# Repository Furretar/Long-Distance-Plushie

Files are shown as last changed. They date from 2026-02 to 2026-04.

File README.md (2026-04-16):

# Overview

#### The device has 4 modes: active, normal checks, slow checks, and off.
- After connecting to a network and MQTT, it starts in normal mode and wakes up every 15 seconds to check for commands.
- After reading a command, it will become active and stay awake for 2 minutes. It can recieve messages instantly in this mode.
- After 2 days of inactivity, the device enteres slow mode, and only checks every 30 seconds. (these values can be changed in the config)
- After sending the command `off`, the device will go into deep sleep, and can only be woken up with the button.

#### The LED has 6 colors.
- Red: Connecting to WiFi
- Blue: Connecting to MQTT
- Green: Active
- Yellow: Both devices are active
- White: This device is vibrating
- Magenta: Other device is vibrating
- Cyan: Sending vibrate command, other device should wake up soon

#### WiFi
The ESP32 communicates over WiFi using MQTT. It has a hardcoded default WiFi network. It will automatically try to connect to this when it first starts up. You can add networks to the config via the serial terminal or an MQTT command. After connecting to a new network, the default network is changed to the new network. The device will try 2 times to connect to the last connected network. If these attempts both fail, it will try every other network saved in the config. If it connects to a new network, it will move that network to the front of the list and set the last connected network. It repeats this process 3 times, then it gives up and goes to sleep for 2x the slow check interval (60 seconds) before trying again. If the device can't connect to any network, it will need to be connected to a computer with [Arudino IDE](https://www.arduino.cc/en/software/) to send a command to add a network.

#### MQTT
The LED displays the device's status while it's trying to connect to the MQTT server (and can't send any messages). It will shine red while connecting to WiFi, and shine blue while connecting to MQTT. After failing an MQTT connection 2 times, the device will go sleep for 2x the slow check interval (60 seconds) before trying again. Pushing the button will make it attempt a connection again.

#### Button
While connected, the button will trigger the other device's motor at 20% strength (can be changed). If the button is held for longer than 10 seconds the motor will automatically turn off.

#### Battery
The battery can be recharged by plugging in the device, and the voltage can be seen in the MQTT info topic. It's estimated the battery life would last 20 days with 1 hour of active time and 23 hours of normal checks a day. It's also estimated the battery is about to die at 3.3 volts.

# MQTT Broker Setup
If you don't want self host your MQTT broker, I recommend the service [EMQX](https://www.emqx.com/en/MQTT/public-MQTT5-broker). The free tier allows 1,000 devices to be connected, with 1,000,000 active minutes and 1 GB of data per month. This should be way more than enough for this project. Just make an account, make a project, set a username and password in `Access Control->Authorization` (set both to `a` so it works automatically with this code), and you can access the MQTT host in `Deployment Overview`. Just set the host url in the `LDP-ESP32-Code.ino` file near the top.

Example: `const char* defaultMqttHost = "lc600a99.ala.us-east-1.emqxsl.com"`



# Sending Commands:
Commands can be sent to the device through the `Iot MQTT Panel` app. You can also see the status of each device, and they will display messages about their mode, when they vibrate, and current voltage. 

- the dashboard settings require a name (anything)
- an ID (anything)
- a broker address (example): `lc600a99.ala.us-east-1.emqxsl.com`
- a port: `8883`
- network protocol: TCP-SSL
- and in additional options, a username: `a`
- and a password: `a`
  
After connecting, add 5 panels. The available topics are `ESP32_1`, `ESP32_2`, and `info`. add a text input and output for ESP32_1 and ESP32_2, and a text output for info. 

# Commands
open the IoT MQTT Panel app on iOS or android to send commands through MQTT, or send commands in serial monitor in Arudino IDE

`run` - toggles the motor on

`run 100` - toggles the motor with 100% strength

`stop` - toggles the motor off

`print config` - prints config to the terminal

`config [key] [value]`, example: `config strength 100` - changes value of the entry in the config

`delete config` - deletes the config and recreates it with default values

`add network [name] [password]` - adds a network with the name/ssid and password

`delete network [ssid]` - deletes the WiFi network entry with the listed name/ssid

`print voltage` - prints voltage to the terminal and info topic MQTT

`sleep` - puts device to sleep, will wake up after normal check time

`off` - puts device to sleep, can only be woken with the button WIP

`var all` - prints the value of global variables, for debugging

You may need to wait to send a command if the device is trying to connect to MQTT.

# Construction Notes
- To build this project, you can reference the item list below and `LDP-Wiring.svg` file in this repository. There is also a 3D model file `LDP-housing-model.stl` that can be printed to house the project once constructed.
- [info about the ESP32 xiao c3.](https://wiki.seeedstudio.com/XIAO_ESP32C3_Getting_Started/)
- The LED can't use pins D9 (GPIO21) or D7 (GPIO20) because they can't be turned off while asleep, and will cause the LED to dimly glow. 
- There is tape on the LED to prevent the pins from touching. This isn't strictly necessary, and anything to stop the pins from touching will work. 
- ESP32 battery wires should all be lead out of the back, away from the usb port. there should be 2 pairs of wires on the BAT-/BAT+ pads, 1 pair connected to the battery holder, and 1 pair of jumper cables to power the board. (If you solder another pair of 220k resistors on the pads, you don't need to attach the 220k resistors as shown in the picture [as described here](https://wiki.seeedstudio.com/XIAO_ESP32C3_Getting_Started/#check-the-battery-voltage).)
  
pin_map-2

# Wiring Pictures
Uploading LDP-Wiring.svg…

Unfortunately I made 2 mistakes in my soldering in these examples. You should refer to the fritzing model instead. The blue and purple wires are unnecessary, you only need 1 pair of jumper cables attached to the BAT+/BAT- pads on the ESP32. The header pins are also crooked on my ESP32 in this example. 

pin_map-2

pin_map-2

pin_map-2

pin_map-2

# Item list
[seeed ESP32 xiao c3](https://www.amazon.com/dp/B0DGX3LSC7/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)

[8000-16000RPM Motor](https://www.amazon.com/dp/B07KYLZC1S/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)

[2 inch arcade buttons](https://www.amazon.com/dp/B07V55YPP3/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)

[1￵8￵6￵5￵0 Rechargeable Batter￵y](https://www.amazon.com/dp/B0DF6CPJFR/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)

[18650 Battery Holders](https://www.amazon.com/dp/B0BJV7SK5D/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)

[Common Cathode RGB LEDs](https://www.amazon.com/dp/B077XGF3YR/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)

[mini bread boards](https://www.amazon.com/dp/B09YXQJMTG/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)

[Heat Resistant Polyimide Tape](https://www.amazon.com/dp/B0DZCTB4KG?ref=ppx_yo2ov_dt_b_fed_asin_title&th=1)

[2n2222 transistors](https://www.amazon.com/dp/B07T61SY9Y/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)

[diode](https://www.amazon.com/dp/B0FC2CTBJR/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)

[Breadboard Jumper Wire kit](https://a.co/d/aZJ2nzj)

[resistors](https://www.amazon.com/dp/B0F4P352BB/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)

[header pins](https://www.amazon.com/dp/B07PKKY8BX/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)

# (WIP) Handling Blocked Public Networks
This is an overview to remind myself, this solution is not implemented in the code yet. On some public WiFi networks, the host `emqxsl.com` is blocked, and you will not be able to send any MQTT messages over the network. This is the case on my university's campus WiFi. You can bypass this by hosting a web service that receives the commands and sends them to EMQX. To do this,  I recommend the service [Render.com](https://render.com/). 
- Clone this github repository
- Go to `Projects`
- `Deploy A Web Service`
- Select this repository
- Set `Language` to `Node`
- Set `Root Directory` as `./Optional-MQTT-Bridge`
- Set `Build Command` to `npm install`
- Set `Start Command` to `npm start`

You can now use the web service link `https://example.onrender.com`  to send messages to your MQTT broker. You can send messages using the ESP32 like this:
```
http.begin(client, "https://example.onrender.com/publish");
http.addHeader("Content-Type", "application/json");
http.POST("{\"topic\":\"example_topic\",\"message\":\"hello\"}");
```

Or the command line like this:

`curl -X POST https://long-distance-plushie.onrender.com/publish -H "Content-Type: application/json" -d '{"topic": "example_topic", "message": "hello"}'`

However, there's also a login capture page when sending requests over HTTPS on my university's network. I don't know of a way to navigate the login portal on the ESP32, so one way to bypass this is MAC address spoofing. You can change your computer's MAC address, authenticate the WiFi network, set your ESP32's MAC address to match, then change your computer's MAC address back. There can't be 2 devices with the same MAC address on the same network. I could add a flag to the code to switch to always using the bridge, as well as a variable to store a MAC address. I don't plan on implementing this currently and will test out using a hotspot instead.

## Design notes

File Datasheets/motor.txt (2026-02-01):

DC Coreless Motor Built-in Vibration Waterproof 1.5-3v 8000-16000RPM Motor for Electric Toothbrush 7x25mm 5PCS
Brand 	tatoko
Speed 	16000 RPM
Voltage 	3 Volts
Horsepower 	0.06 Watts
Product Dimensions 	0.27"W x 0.96"H
    Size: 7x25mm:IP67
    Voltage: 1.5-3v Speed: 8000-16000 Power: 0.01-0.06W Torque: 0.3g.cm-3g.cm (NM)

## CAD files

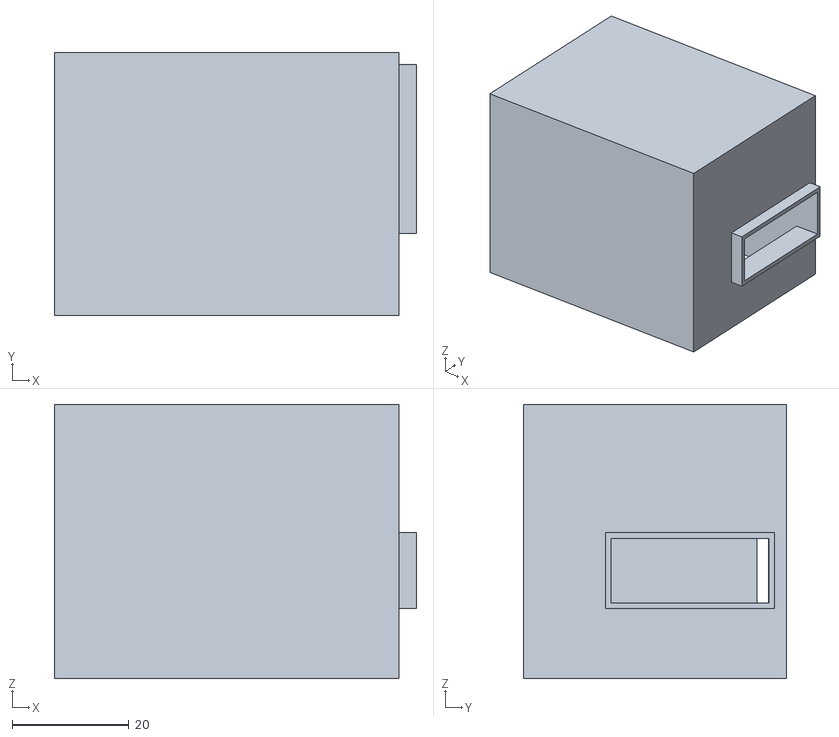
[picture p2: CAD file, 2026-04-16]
LDP-housing-model.stl
62.0 x 45.0 x 47.0

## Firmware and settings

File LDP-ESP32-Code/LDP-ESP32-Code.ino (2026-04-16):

#include <WiFi.h>
#include <PubSubClient.h>
#include <WiFiClientSecure.h>
#include <LittleFS.h>  // for logging
#include <ArduinoJson.h>
#include "esp_sleep.h"  // for deep sleep
#include <time.h>

#define BATTERY_PIN D0
#define MOTOR_PIN D10
#define BUTTON_PIN D1  // GPIO 3, RTC capable/can wake up from deep sleep
#define RED_PIN D5
#define GREEN_PIN D4
#define BLUE_PIN D3

// change for each esp32
const int thisNum = 1;

// change for other setups
const char* defaultMqttHost = "";
const char* userNetwork = "";
const char* userPassword = "";

const int defaultMqttPort = 8883;
const char* defaultMqttUser = "a";
const char* defaultMqttPass = "a";
const char* defaultInfoTopic = "info";

// topics
const int targetNum = thisNum == 1 ? 2 : 1;
String thisTopic = String("esp32_") + String(thisNum);
String targetTopic = String("esp32_") + String(targetNum);
String thisPing = String("ping_") + String(thisNum);
String targetPing = String("ping_") + String(targetNum);

// default config values
const int defaultCheckMqttTime = 100;               // ms, default 200, time awake to read retained mqtt messages
const int defaultStayAwakeAfterCommand = 120;       // seconds, default 120
const int defaultMotorTimeout = 10000;              // ms, default 10,000
const int defaultNormalCheck = 15ULL * 1000000ULL;  // microseconds, default 15,000,000, sleep for this long before waking up to check again
const int defaultSlowCheck = 30ULL * 1000000ULL;    // microseconds, default 30,000,000
const int defaultMaxPwm = 150;                      // out of 255, motor rated for 3 volts but powered by 3.7, default 150
const int defaultBrightness = 20;                   // percent max brightness
const int defaultStrength = 20;                     // percent of max motor strength, default 20
const int defaultTimeUntilSlowCheckMode = 2 * (60 * 60 * 24);

// config variables
RTC_DATA_ATTR int checkMqttTime;
RTC_DATA_ATTR unsigned long stayAwakeAfterCommand;
RTC_DATA_ATTR unsigned long motorTimeout;
RTC_DATA_ATTR unsigned long long normalCheck;
RTC_DATA_ATTR unsigned long long slowCheck;
RTC_DATA_ATTR int maxPwm;
RTC_DATA_ATTR int mqttPort;
RTC_DATA_ATTR char mqttHost[128];
RTC_DATA_ATTR char mqttUser[64];
RTC_DATA_ATTR char mqttPass[64];
RTC_DATA_ATTR char infoTopic[64];
RTC_DATA_ATTR int strength;
RTC_DATA_ATTR int brightness;
RTC_DATA_ATTR char default_ssid[32] = "";
RTC_DATA_ATTR char default_password[64] = "";
RTC_DATA_ATTR time_t timeUntilSlowCheckMode;

// non config rtc
RTC_DATA_ATTR bool debugMqttFailed = false;
RTC_DATA_ATTR bool firstBoot = true;
RTC_DATA_ATTR bool slowCheckMode = false;
RTC_DATA_ATTR time_t timeLastActive;

// global variables
bool offSwitch = false;
bool runMotor = false;
bool clearCommand = false;
bool clearPing = false;
bool variablesSet = false;
bool commandReceivedThisBoot = false;
bool otherAwake = false;
bool mqttConnected = false;
esp_sleep_wakeup_cause_t wakeupReason = esp_sleep_get_wakeup_cause();
volatile bool stayAwake = (wakeupReason == ESP_SLEEP_WAKEUP_GPIO);
int lastButtonState = HIGH;
unsigned long motorStart = 0;
unsigned long mqttConnectTime = 0;
StaticJsonDocument<1024> doc;
WiFiClientSecure wifi;
PubSubClient mqtt(wifi);


// led variables
int currentR = 0;
int currentG = 0;
int currentB = 0;
int bothAwakeR = 70;
int bothAwakeG = 70;
int bothAwakeB = 0;
int thisAwakeR = 0;
int thisAwakeG = 70;
int thisAwakeB = 0;

// sync variable
unsigned long lastPingSent = 0;
unsigned long lastPongReceived = 0;
const int pingInterval = 500;
const int pongTimeout = 2000;  // consider other ESP asleep after 2s

// track date
const char* ntpServer = "pool.ntp.org";
const long gmtOffsetSec = -5 * 3600;  // adjust timezone
RTC_DATA_ATTR time_t lastVoltageReport = 0;

void initTime() {
  configTime(gmtOffsetSec, 0, ntpServer);
  struct tm timeinfo;
  if (!getLocalTime(&timeinfo)) {
    Serial.println("Failed to obtain time");
    return;
  }
}

// lock pins when sleeping so leaking current doesn't cause led to glow
void goToSleep(unsigned long timeLength) {
  // force pin LOW so LED is off
  digitalWrite(RED_PIN, LOW);
  digitalWrite(GREEN_PIN, LOW);
  digitalWrite(BLUE_PIN, LOW);

  // lock the pin state
  gpio_hold_en((gpio_num_t)RED_PIN);
  gpio_hold_en((gpio_num_t)GREEN_PIN);
  gpio_hold_en((gpio_num_t)BLUE_PIN);

  // report sleep
  String msg = "";
  if (timeLength > 0) {
    esp_sleep_enable_timer_wakeup(timeLength);
    msg = "sleeping for: " + String(timeLength / 1000000.0) + " seconds";

  } else {
    msg = "sleeping indefinitely";
  }

  Serial.println(msg);
  if (mqttConnected) {
    send_mqtt(infoTopic, msg);
    mqtt.loop();
    delay(50);
  }

  gpio_deep_sleep_hold_en();  // keep hold during deep sleep
  esp_deep_sleep_start();     // enter deep sleep
}


void set_led(int r, int g, int b) {
  currentR = r;
  currentG = g;
  currentB = b;

  r = min(255, int(r * brightness * 0.01));
  g = min(255, int(g * brightness * 0.01));
  b = min(255, int(b * brightness * 0.01));

  analogWrite(RED_PIN, r);
  analogWrite(GREEN_PIN, g);
  analogWrite(BLUE_PIN, b);
}

void led_off() {
  analogWrite(RED_PIN, 0);
  analogWrite(GREEN_PIN, 0);
  analogWrite(BLUE_PIN, 0);
}


void loadString(char* dst, size_t dstSize, JsonDocument& doc, const char* key, const char* def) {
  const char* src = doc[key] | def;
  strncpy(dst, src, dstSize - 1);
  dst[dstSize - 1] = '\0';
}



// create config with default values
void setup_config() {
  if (!LittleFS.begin(true)) {
    Serial.println("LittleFS mount failed");
    return;
  }

  // wipe memory from doc
  doc.clear();

  // create file if it doesn't exist
  if (!LittleFS.exists("/networks.json")) {
    Serial.println("creating networks.json");
    File file = LittleFS.open("/networks.json", "w");

    // initialize keys
    JsonArray networks = doc.createNestedArray("networks");
    JsonObject defaultNetwork = networks.createNestedObject();
    defaultNetwork["ssid"] = userNetwork;
    defaultNetwork["password"] = userPassword;
    doc["checkMqttTime"] = defaultCheckMqttTime;
    doc["stayAwakeAfterCommand"] = defaultStayAwakeAfterCommand;
    doc["motorTimeout"] = defaultMotorTimeout;
    doc["normalCheck"] = defaultNormalCheck;
    doc["slowCheck"] = defaultSlowCheck;
    doc["maxPwm"] = defaultMaxPwm;
    doc["mqttHost"] = defaultMqttHost;
    doc["mqttPort"] = defaultMqttPort;
    doc["mqttUser"] = defaultMqttUser;
    doc["mqttPass"] = defaultMqttPass;
    doc["infoTopic"] = defaultInfoTopic;
    doc["strength"] = defaultStrength;
    doc["brightness"] = defaultBrightness;
    doc["timeUntilSlowCheckMode"] = defaultTimeUntilSlowCheckMode;

    // write to file and close
    serializeJsonPretty(doc, file);
    file.close();
    Serial.println("networks.json created");
  }

  // open file for reading
  File file = LittleFS.open("/networks.json", "r");
  if (!file) {
    Serial.println("failed to open networks.json");
    return;
  }

  // check errors
  DeserializationError err = deserializeJson(doc, file);
  file.close();
  if (err) {
    Serial.print("Failed to parse networks.json: ");
    Serial.println(err.c_str());
    return;
  }

  // load vars from config to RTC memory
  load_config_vars();
}

// print the config in serial terminal and send it to mqtt if possible
void print_config_serial_mqtt() {
  Serial.println("networks.json:");
  serializeJsonPretty(doc, Serial);
  Serial.println();

  if (mqttConnected) {
    mqtt.setBufferSize(2048);
    String configMessage;
    serializeJsonPretty(doc, configMessage);
    send_mqtt(String(infoTopic), configMessage);
  }
}

// set global variables with config
void load_config_vars() {
  checkMqttTime = doc["checkMqttTime"];
  stayAwakeAfterCommand = doc["stayAwakeAfterCommand"];
  motorTimeout = doc["motorTimeout"];
  normalCheck = doc["normalCheck"];
  slowCheck = doc["slowCheck"];
  maxPwm = doc["maxPwm"];
  mqttPort = doc["mqttPort"];
  loadString(mqttUser, sizeof(mqttUser), doc, "mqttUser", defaultMqttUser);
  loadString(mqttPass, sizeof(mqttPass), doc, "mqttPass", defaultMqttPass);
  loadString(infoTopic, sizeof(infoTopic), doc, "infoTopic", defaultInfoTopic);
  loadString(mqttHost, sizeof(mqttHost), doc, "mqttHost", defaultMqttHost);
  strength = doc["strength"];
  brightness = doc["brightness"];
  timeUntilSlowCheckMode = doc["timeUntilSlowCheckMode"];
}

// send notification to info topic
void send_mqtt(String topic, String message) {
  message = String(thisTopic) + ": " + message;
  if (mqtt.publish(topic.c_str(), message.c_str())) {
  } else {
    Serial.println("Message failed to send.");
  }
}

// delete config
void delete_config() {
  if (LittleFS.exists("/networks.json")) {
    if (LittleFS.remove("/networks.json")) {
      Serial.println("networks.json deleted successfully");
    } else {
      Serial.println("Failed to delete networks.json");
      return;
    }
  } else {
    Serial.println("networks.json does not exist");
  }
  setup_config();
  print_config_serial_mqtt();
}

// add a wifi network to the config
void add_network(const char* ssid, const char* password) {
  JsonArray networks = doc["networks"].as<JsonArray>();
  if (!networks) {
    networks = doc.createNestedArray("networks");
  }
  JsonObject net = networks.createNestedObject();
  net["ssid"] = ssid;
  net["password"] = password;

  File file = LittleFS.open("/networks.json", "w");
  serializeJson(doc, file);
  file.close();

  Serial.println("Network added: " + String(ssid));
  print_config_serial_mqtt();
}

// remove a wifi network from the config
void delete_network(const char* ssid) {
  JsonArray networks = doc["networks"].as<JsonArray>();
  if (!networks) return;
  for (int i = 0; i < networks.size(); i++) {
    JsonObject net = networks[i];
    if (net["ssid"] == ssid) {
      networks.remove(i);
      Serial.println("Network deleted: " + String(ssid));
      break;
    }
  }
  File file = LittleFS.open("/networks.json", "w");
  serializeJson(doc, file);
  file.close();

  print_config_serial_mqtt();
}

// set a value in the config for ints
void set_config_value_int(const char* key, int new_value) {
  if (!LittleFS.begin()) {
    Serial.println("LittleFS mount failed");
    return;
  }

  File file = LittleFS.open("/networks.json", "r");
  if (!file) {
    Serial.println("Failed to open networks.json for reading");
    return;
  }

  DeserializationError err = deserializeJson(doc, file);
  file.close();
  if (err) {
    Serial.print("Failed to parse networks.json: ");
    Serial.println(err.c_str());
    return;
  }

  doc[key] = new_value;

  File fileOut = LittleFS.open("/networks.json", "w");
  if (!fileOut) {
    Serial.println("Failed to open networks.json for writing");
    return;
  }
  serializeJsonPretty(doc, fileOut);
  fileOut.close();

  Serial.print("Updated ");
  Serial.print(key);
  Serial.print(" to ");
  Serial.println(new_value);
}

// set a value in the config for strings
void set_config_value_string(const char* key, const char* value) {
  if (!LittleFS.begin()) {
    Serial.println("LittleFS mount failed");
    return;
  }

  File file = LittleFS.open("/networks.json", "r");
  if (!file) {
    Serial.println("Failed to open networks.json for reading");
    return;
  }

  DeserializationError err = deserializeJson(doc, file);
  file.close();
  if (err) {
    Serial.print("failed to parse networks.json: ");
    Serial.println(err.c_str());
    return;
  }

  doc[key] = value;

  File fileOut = LittleFS.open("/networks.json", "w");
  if (!fileOut) {
    Serial.println("failed to open networks.json for writing");
    return;
  }
  serializeJsonPretty(doc, fileOut);
  fileOut.close();
}


// reads and runs commands
void mqtt_callback(char* topic, byte* payload, unsigned int length) {

  unsigned long messageDelay = millis() - mqttConnectTime;

  if (!commandReceivedThisBoot)
    Serial.println("Message arrived after: " + String(messageDelay) + " ms");

  String message = "";
  for (unsigned int i = 0; i < length; i++) {
    message += (char)payload[i];
  }
  handle_command(message);
}

// // scans networks, for debugging
// void scan_print_networks() {
//   Serial.println("scanning available wifi networks...");
//   int networksCount = WiFi.scanNetworks();

//   while (networksCount == 0) {
//     Serial.println("No networks found");
//     networksCount = WiFi.scanNetworks();
//   }

//   Serial.println(String(networksCount) + " networks found");
//   for (int i = 0; i < networksCount; ++i) {
//     String ssid = WiFi.SSID(i);
//     Serial.print(i + 1);
//     Serial.print(": ");
//     Serial.println(ssid);
//   }
// }

// process and run commands
void handle_command(String message) {
  message.trim();

  if (message.equals("")) {
    return;
  }

  // ignore pings when waking and sleeping normally
  bool isPingPong = (message == "ping" || message == "pong");
  if (isPingPong && !stayAwake) {
    return;
  }

  // keep device awake if a command arrives
  if (!isPingPong && !message.startsWith("var")) {
    time(&timeLastActive);
    commandReceivedThisBoot = true;
    stayAwake = true;
    Serial.println("received msg: " + message);
  }

  // run
  if (message.startsWith("run") && !runMotor) {
    int val = message.length() > 4 ? message.substring(4).toInt() : strength;
    if (val >= 0 && val <= 100) strength = val;
    int motorStrength = (val * maxPwm) / 100;
    runMotor = true;
    motorStart = millis();
    set_led(255, 255, 255);
    analogWrite(MOTOR_PIN, motorStrength);
    Serial.println("Motor ON (strength: " + String(val) + "%)");
  }

  // run
  else if (message.equals("stop")) {
    runMotor = false;
    motorStart = 0;
    analogWrite(MOTOR_PIN, 0);
    Serial.println("stopping");
  }

  // config
  else if (message.startsWith("config")) {
    String params = message.substring(7);
    params.trim();

    int firstSpace = params.indexOf(' ');
    if (firstSpace < 0) {
      Serial.println("usage: config <key> <value>");
      return;
    }

    String key = params.substring(0, firstSpace);
    String valueStr = params.substring(firstSpace + 1);
    valueStr.trim();

    // list of integer keys
    const char* intKeys[] = {
      "strength", "maxPwm", "motorTimeout",
      "checkMqttTime", "stayAwakeAfterCommand", "normalCheck", "slowCheck", "brightness", nullptr
    };
    // list of string keys
    const char* stringKeys[] = {
      "mqttHost", "mqttPort", "mqttUser", "mqttPass", "infoTopic", nullptr
    };
    bool handled = false;

    // check if it's an integer key
    for (int i = 0; intKeys[i] != nullptr; i++) {
      if (key == intKeys[i]) {
        int valueInt = valueStr.toInt();
        set_config_value_int(key.c_str(), valueInt);
        handled = true;
        break;
      }
    }

    // check if it's a string key
    if (!handled) {
      for (int i = 0; stringKeys[i] != nullptr; i++) {
        if (key == stringKeys[i]) {
          set_config_value_string(key.c_str(), valueStr.c_str());
          handled = true;
          break;
        }
      }
    }
    if (!handled) {
      Serial.println("Unknown config key: " + key);
    }
    print_config_serial_mqtt();
  }

  // add network
  else if (message.startsWith("add network")) {
    String params = message.substring(12);
    int spaceIndex = params.indexOf(' ');
    String ssid = spaceIndex > 0 ? params.substring(0, spaceIndex) : params;
    String password = spaceIndex > 0 ? params.substring(spaceIndex + 1) : "";
    add_network(ssid.c_str(), password.c_str());
  }

  // delete network
  else if (message.startsWith("delete network")) {
    String ssid = message.substring(15);
    delete_network(ssid.c_str());
  }

  // delete config
  else if (message.equals("delete config")) {
    delete_config();
  }

  // print config
  else if (message.startsWith("print config")) {
    print_config_serial_mqtt();
  }

  // print voltage
  else if (message.startsWith("print voltage")) {
    read_and_print_voltage();
  }

  // off
  else if (message.equals("off")) {
    // clear retained message or it'll reread and sleep forever
    mqtt.publish(thisTopic.c_str(), "", true);
    goToSleep(0);
  }

  // sleep
  else if (message.startsWith("sleep")) {
    // clear retained message or it'll reread and sleep forever
    mqtt.publish(thisTopic.c_str(), "", true);
    goToSleep(normalCheck);
  }

  // ping
  else if (message.equals("ping")) {
    mqtt.publish(targetPing.c_str(), "pong");
  }

  // pong
  else if (message.equals("pong")) {
    lastPongReceived = millis();
    otherAwake = true;
  }

  // var all
  else if (message == "var all") {
    String msg = "----- VARIABLES -----\n";

    msg += "offSwitch: " + String(offSwitch) + "\n";
    msg += "runMotor: " + String(runMotor) + "\n";
    msg += "clearCommand: " + String(clearCommand) + "\n";
    msg += "clearPing: " + String(clearPing) + "\n";
    msg += "variablesSet: " + String(variablesSet) + "\n";
    msg += "commandReceivedThisBoot: " + String(commandReceivedThisBoot) + "\n";
    msg += "lastButtonState: " + String(lastButtonState) + "\n";

    msg += "motorStart: " + String(motorStart) + "\n";
    msg += "mqttConnectTime: " + String(mqttConnectTime) + "\n";

    msg += "stayAwake: " + String(stayAwake) + "\n";
    msg += "otherAwake: " + String(otherAwake) + "\n";
    msg += "mqttConnected: " + String(mqttConnected) + "\n";

    msg += "lastPingSent: " + String(lastPingSent) + "\n";
    msg += "lastPongReceived: " + String(lastPongReceived) + "\n";

    msg += "pingInterval: " + String(pingInterval) + "\n";
    msg += "pongTimeout: " + String(pongTimeout) + "\n";

    msg += "debugMqttFailed: " + String(debugMqttFailed) + "\n";
    msg += "firstBoot: " + String(firstBoot) + "\n";
    msg += "slowCheckMode: " + String(slowCheckMode) + "\n";

    // convert timeLastActive to readable format
    time_t adjustedTime = timeLastActive + gmtOffsetSec;
    struct tm timeinfo;
    if (localtime_r(&adjustedTime, &timeinfo)) {
      char buffer[32];
      strftime(buffer, sizeof(buffer), "%Y-%m-%d %H:%M:%S", &timeinfo);
      msg += "timeLastActive: " + String(buffer) + "\n";
    } else {
      msg += "timeLastActive: invalid\n";
    }

    Serial.println(msg);
    if (mqttConnected) {
      mqtt.setBufferSize(2048);
      send_mqtt(infoTopic, msg);
      mqtt.loop();
      delay(50);
    }
  }

  // else invalid
  else {
    Serial.println("Invalid command: " + message);
  }

  if (!isPingPong) {
    clearCommand = true;
  }
}
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
void loop() {

  int buttonState = digitalRead(BUTTON_PIN);

  // keep device active while button is held
  if (buttonState == LOW) {
    time(&timeLastActive);
  }

  // button pressed
  if (buttonState == LOW && lastButtonState == HIGH) {
    stayAwake = true;
    if (otherAwake) {
      set_led(255, 0, 255);
    } else {
      set_led(0, 255, 255);
    }

    time(&timeLastActive);
    commandReceivedThisBoot = true;
    Serial.println("sending run to other esp32");
    mqtt.publish(targetTopic.c_str(), "run", true);
  }
  // button released, stop motor
  if (buttonState == HIGH && lastButtonState == LOW) {
    stayAwake = true;
    time(&timeLastActive);
    commandReceivedThisBoot = true;
    Serial.println("sending stop to other esp32");
    mqtt.publish(targetTopic.c_str(), "stop", true);
  }

  // clear mqtt messages
  if (clearCommand) {
    mqtt.publish(thisTopic.c_str(), "", true);
    clearCommand = false;
  }
  if (clearPing) {
    mqtt.publish(thisPing.c_str(), "", true);
    clearPing = false;
  }

  lastButtonState = buttonState;
  mqtt.loop();

  // motor timeout
  if (runMotor && millis() - motorStart > motorTimeout) {
    runMotor = false;
    led_off();
    analogWrite(MOTOR_PIN, 0);
    Serial.println("Motor timed out");
  }

  // read terminal commands
  if (Serial.available()) {
    String message = Serial.readStringUntil('\n');
    handle_command(message);
  }

  // wait for retained messages to arrive
  static unsigned long loopStartTime = 0;
  if (loopStartTime == 0) {
    loopStartTime = millis();
  }

  time_t now;
  time(&now);
  unsigned long timeSincemqtt = millis() - mqttConnectTime;
  double timeSinceCommand = difftime(now, timeLastActive);

  // sleep if not running motor
  if (!runMotor && timeSincemqtt > checkMqttTime && (!stayAwake || timeSinceCommand > stayAwakeAfterCommand)) {
    Serial.flush();
    if (!slowCheckMode) {
      goToSleep(normalCheck);
    } else {
      goToSleep(slowCheck);
    }
  }

  if (stayAwake && millis() - lastPingSent > pingInterval) {
    lastPingSent = millis();
    mqtt.publish(targetPing.c_str(), "ping");
  }

  if (millis() - lastPongReceived > pongTimeout) {
    otherAwake = false;
  }

  static unsigned long lastLedUpdate = 0;
  if (millis() - lastLedUpdate > 100) {
    lastLedUpdate = millis();

    if (!runMotor && buttonState == HIGH && stayAwake) {
      if (!otherAwake) {
        set_led(thisAwakeR, thisAwakeG, thisAwakeB);
      } else {
        set_led(bothAwakeR, bothAwakeG, bothAwakeB);
      }
    }
  }
}

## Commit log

2026-02-01 update motor control
2026-02-01 add fritzing schematic
    [wireless vibrating plushie schematic.fzz]
2026-02-03 make default network rtc
    [wireless vibrating plushie schematic.fzz]
2026-02-03 Add button vibration feature to README
2026-02-04 added button hold logic
2026-02-04 button logic fixed
2026-02-04 update wiring for button
    [wireless vibrating plushie schematic.fzz]
2026-02-04 rewire to power with esp32
    [wireless vibrating plushie schematic.fzz]
2026-02-16 Update links for battery holders and add components
    Updated battery holder link and added new components links.
2026-02-17 print config to info and serial window
    [circuit schematic.fzz]
2026-02-18 fix button logic
2026-03-07 wakes on button press
    [circuit schematic.fzz]
2026-03-07 led and sync logic
    [circuit schematic.fzz]
2026-03-08 Add to-do item for transistor to LED
2026-03-08 tweak leds
    2 different colors for when sending a command while other device is and isnt connected, and dont turn off the led when sending stop
2026-03-09 fix led dimly glowing, change wiring
    [circuit schematic.fzz, circuit.fzz]
2026-03-09 Update README to reflect current to-do items
    Removed completed tasks from the to-do list in README.
2026-03-09 change wiring
    [circuit.fzz]
2026-03-09 Add circuit diagram and construction notes to README
2026-03-09 add svg
    [circuit.fzz]
2026-03-09 Add wiring section with circuit diagram
    Added a section on wiring with a circuit diagram.
2026-04-03 update wiring and model
    [LDP-housing-model.stl, circuit.fzz]
2026-04-05 update wiring
    [LDP-Wiring.fzz, circuit.fzz]
2026-04-16 update 3d model
    [LDP-housing-model.stl]
